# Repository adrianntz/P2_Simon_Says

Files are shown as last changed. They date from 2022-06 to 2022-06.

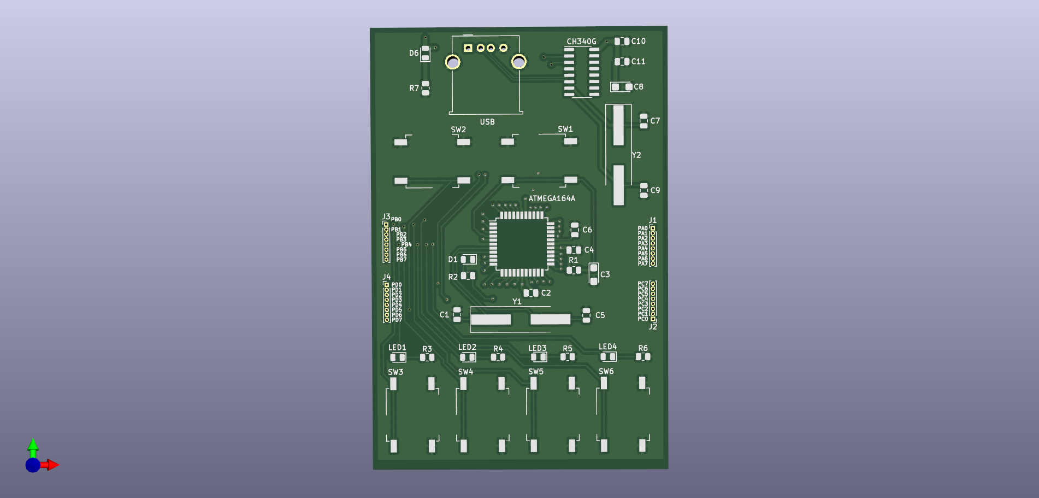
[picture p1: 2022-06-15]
Hardware/Simon Says PCB Layout.png

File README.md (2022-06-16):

# P2_Simon_Says
Proiect Simplu proiectat cu microcontroller AVR ATMEGA164A pentru a creea un joc simplu de tip Simon Says, folosind 4 butoane pentru user input si 4 led-uri pentru system output. 

## Inspiratie Proiect
Ideea de functionare a jocului a fost preluata din acest proiect pe arduino:

IMAGE ALT TEXT HERE (https://www.youtube.com/watch?v=xLLTxN_UBnI)

https://youtu.be/xLLTxN_UBnI

## Firmware Architecture
Bootloader-ul pentru Atmega164A este deja incarcat inainte de primirea chip-ului. Firmware-ul poate fi flashed folosind programul AvrBuster.exe
Firmware-ul pentru Atmega164A este scris in C folosind compilatorul CodeVisionAVR ANSI C Compiler si IDE-ul CodeVisionAVR. Codul in C  a fost creat folosind Code Wizard-ul IDE-ului.
Pentru jocul Simon Says vom folosi doar Portul B al microcontrollerului. Astfel, cu Code Wizard am initializat Pinii PB0->3 ca input si conectati la rezistorul pull-up intern, acesti pini fiind conectati la switch-uri, iar pinii PB4->7 sunt de tip output prin care aprindem LED-urile.
Codul are ca structura principala doi vectori de lungime MAX_LEVEL, unul fiind lista de secvente a nivelului si al doilea fiind secventa introdusa de catre jucator.
Astfel, lungimea jocului poate fi setata folosind MAX_LEVEL. La pornirea firmware-ului se umple vectorul nivelului cu valori randomizate intre 0 si 4. De-a lungul jocului se completeaza si vectorul cu secventele introduse de jucator, si se vor compara ce doi vetori. In momentul in care se greseste o secventa sau se ajunge la lungimea maxima, se termina jocul si se reseteaza vectorii.
De asemenea Firmware-ul are implementat o dificultate a jocului, anume viteza afisarii secventei curente. Cu cat este mai avansat jocul intr-o secventa mai mare, aceasta viteza creste, facand jocul mai dificil cu cat te joci mai mult.

Utilizare Memorie Firmware:
EEPROM usage: 0 byte(s), 0.0% of EEPROM

Program size: 646 words (1292 bytes), 7.9% of FLASH

RAM Global variables size: 404 byte(s)

Estimated Data Stack usage: 6 byte(s)

(Informatie data de compilator)

## Hadware Description
Placuta THT este compusa dintr-un microcontroller ATMEGA164A cu footprint THD si componentele sale auxiliare (condensatoare, quartz si un LED pentru verificare), iar portul A al microcontrollerului este impartit jumate in input si output. Jumatea de input a portului B este conectat la 4 butoane la GND, iar jumatea de output este conectat la 4 led-uri. Alimentarea se face printr-un USB bridge bazat pe chip-ul CH340G USB to Serial Converter.

Varianta SMD introduce un package mai mic pentru toate componentele, ATMEGA164A fiind pe footprint TQFP si toate rezistoarele, condensatoare si led-urile pe footprint 0805. Bridge-ul USB to Serial este incorporat in placuta conectat la un port micro-USB pus pe placuta.
## Hardware Schematic 
Simon Says Schematic
## Hardware PCB Layout


## BOM 

| Component Count: | 39 | | | |
|---|---|---|---|---|
| Ref | Qnty | Value | Footprint | Description |
| C1, C5, | 2 | 18p | Capacitor_SMD:C_0805_2012Metric | Capacitor symbol for simulation only |
| C2, C4, C6, C11, | 4 | 100n | Capacitor_SMD:C_0805_2012Metric | Capacitor symbol for simulation only |
| C3, | 1 | 1u | Capacitor_Tantalum_SMD:CP_EIA-3216-18_Kemet-A | Polarized capacitor |
| C7, C9, | 2 | 22p | Capacitor_SMD:C_0805_2012Metric | Capacitor symbol for simulation only |
| C8, | 1 | 22u | Capacitor_Tantalum_SMD:CP_EIA-3216-12_Kemet-S | Capacitor symbol for simulation only |
| C10, | 1 | 10n | Capacitor_SMD:C_0805_2012Metric | Capacitor symbol for simulation only |
| D1, | 1 | RED LED | LED_SMD:LED_0805_2012Metric | Light emitting diode |
| D2, D6, | 2 | RED  LED | LED_SMD:LED_0805_2012Metric | Light emitting diode |
| D3, | 1 | GEEN LED | LED_SMD:LED_0805_2012Metric | Light emitting diode |
| D4, | 1 | BLUE LED | LED_SMD:LED_0805_2012Metric | Light emitting diode |
| D5, | 1 | ORANGE LED | LED_SMD:LED_0805_2012Metric | Light emitting diode |
| J1, J2, J3, J4, | 4 | Conn_01x08_Female | Connector_PinHeader_1.00mm:PinHeader_1x08_P1.00mm_Vertical | Generic 1x8 Connector |
| J5, | 1 | USB_A | Connector_USB:USB_A_Molex_67643_Horizontal | USB Type A connector |
| R1, | 1 | 10k | Resistor_SMD:R_0805_2012Metric | Resistor |
| R2, | 1 | 470 | Resistor_SMD:R_0805_2012Metric | Resistor |
| R3, R4, R5, R6, | 4 | 100 | Resistor_SMD:R_0805_2012Metric | Resistor |
| R7, | 1 | 220 | Resistor_SMD:R_0805_2012Metric | Resistor |
| SW1, SW2, SW3, SW4, SW5, SW6,  | 6 | SW_MEC_5G | Button_Switch_SMD:SW_MEC_5GSH9 | MEC 5G single pole normally-open tactile switch |
| U1, | 1 | ATmega16A-AU | Package_QFP:TQFP-44_10x10mm_P0.8mm | 16MHz, 16kB Flash, 1kB SRAM, 512B EEPROM, JTAG, TQFP-44 |
| U2, | 1 | CH340G | Package_SO:SOIC-16_3.9x9.9mm_P1.27mm | USB serial converter, UART, SOIC-16 |
| Y1, | 1 | 20MHz | Crystal:Crystal_SMD_HC49-SD_HandSoldering | Two pin crystal |
| Y2, | 1 | 12MHz | Crystal:Crystal_SMD_HC49-SD_HandSoldering | Two pin crystal |

## Bibliography

https://create.arduino.cc/projecthub/bernieri/genius-game-simon-0e76dc

https://www.youtube.com/watch?v=xLLTxN_UBnI

http://ww1.microchip.com/downloads/en/devicedoc/atmel-8272-8-bit-avr-microcontroller-atmega164a_pa-324a_pa-644a_pa-1284_p_datasheet.pdf

https://cdn.sparkfun.com/datasheets/Dev/Arduino/Other/CH340DS1.PDF

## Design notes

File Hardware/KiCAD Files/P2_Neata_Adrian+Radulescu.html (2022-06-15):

# C:\Users\adyco\OneDrive - Universitatea Politehnica Bucuresti\POLI\ANUL 3 SEM 2\P2\P2 Simon Says Repo\Hardware\P2_Neata_Adrian+Radulescu\P2_Neata_Adrian+Radulescu.sch

6/15/2022 5:18:19 PM

Eeschema (5.1.10)-1

Component Count:39

Ref | Qnty | Value | Part | Footprint | Description | Vendor
C1, C5 | 2 | 18p | pspice:C | Capacitor_SMD:C_0805_2012Metric | Capacitor symbol for simulation only
C2, C4, C6, C11 | 4 | 100n | pspice:C | Capacitor_SMD:C_0805_2012Metric | Capacitor symbol for simulation only
C3 | 1 | 1u | Device:CP | Capacitor_Tantalum_SMD:CP_EIA-3216-18_Kemet-A | Polarized capacitor
C7, C9 | 2 | 22p | pspice:C | Capacitor_SMD:C_0805_2012Metric | Capacitor symbol for simulation only
C8 | 1 | 22u | pspice:C | Capacitor_Tantalum_SMD:CP_EIA-3216-12_Kemet-S | Capacitor symbol for simulation only
C10 | 1 | 10n | pspice:C | Capacitor_SMD:C_0805_2012Metric | Capacitor symbol for simulation only
D1 | 1 | RED LED | Device:LED | LED_SMD:LED_0805_2012Metric | Light emitting diode
D2, D6 | 2 | RED LED | Device:LED | LED_SMD:LED_0805_2012Metric | Light emitting diode
D3 | 1 | GEEN LED | Device:LED | LED_SMD:LED_0805_2012Metric | Light emitting diode
D4 | 1 | BLUE LED | Device:LED | LED_SMD:LED_0805_2012Metric | Light emitting diode
D5 | 1 | ORANGE LED | Device:LED | LED_SMD:LED_0805_2012Metric | Light emitting diode
J1, J2, J3, J4 | 4 | Conn_01x08_Female | Connector:Conn_01x08_Female | Connector_PinHeader_1.00mm:PinHeader_1x08_P1.00mm_Vertical | Generic connector, single row, 01x08, script generated (kicad-library-utils/schlib/autogen/connector/)
J5 | 1 | USB_A | Connector:USB_A | Connector_USB:USB_A_Molex_67643_Horizontal | USB Type A connector
R1 | 1 | 10k | Device:R | Resistor_SMD:R_0805_2012Metric | Resistor
R2 | 1 | 470 | Device:R | Resistor_SMD:R_0805_2012Metric | Resistor
R3, R4, R5, R6 | 4 | 100 | Device:R | Resistor_SMD:R_0805_2012Metric | Resistor
R7 | 1 | 220 | Device:R | Resistor_SMD:R_0805_2012Metric | Resistor
SW1, SW2, SW3, SW4, SW5, SW6 | 6 | SW_MEC_5G | Switch:SW_MEC_5G | Button_Switch_SMD:SW_MEC_5GSH9 | MEC 5G single pole normally-open tactile switch
U1 | 1 | ATmega16A-AU | MCU_Microchip_ATmega:ATmega16A-AU | Package_QFP:TQFP-44_10x10mm_P0.8mm | 16MHz, 16kB Flash, 1kB SRAM, 512B EEPROM, JTAG, TQFP-44
U2 | 1 | CH340G | Interface_USB:CH340G | Package_SO:SOIC-16_3.9x9.9mm_P1.27mm | USB serial converter, UART, SOIC-16
Y1 | 1 | 20MHz | Device:Crystal | Crystal:Crystal_SMD_HC49-SD_HandSoldering | Two pin crystal
Y2 | 1 | 12MHz | Device:Crystal | Crystal:Crystal_SMD_HC49-SD_HandSoldering | Two pin crystal

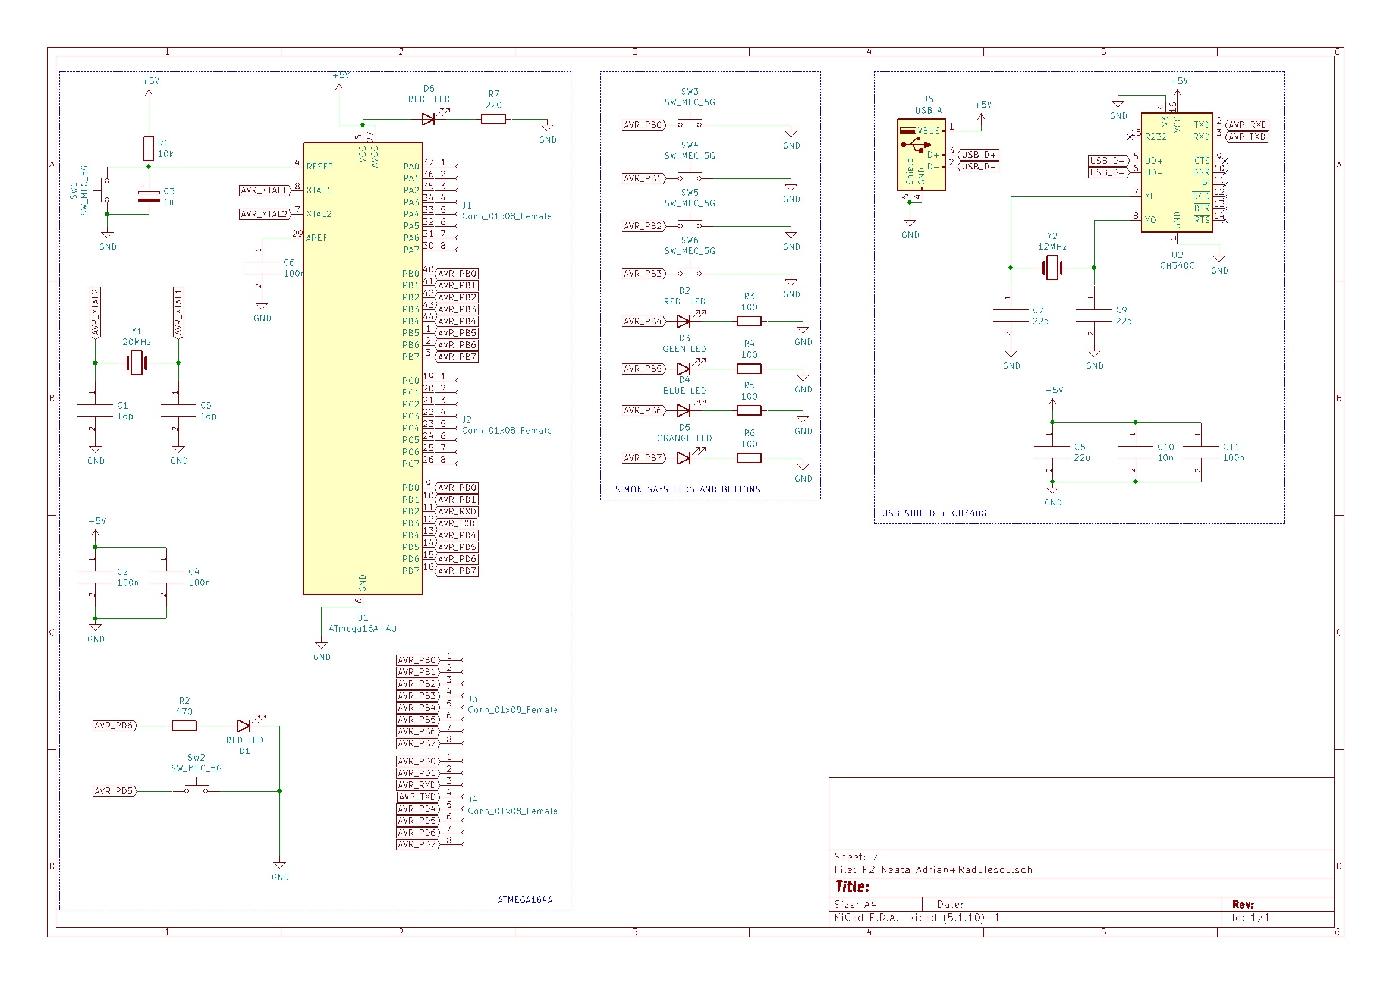
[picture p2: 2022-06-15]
Hardware/Simon Says Schematic.jpg

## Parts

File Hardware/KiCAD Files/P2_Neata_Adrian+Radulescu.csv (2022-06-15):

Source: | C:\Users\adyco\OneDrive - Universitatea Politehnica Bucuresti\POLI\ANUL 3 SEM 2\P2\P2 Simon Says Repo\Hardware\P2_Neata_Adrian+Radulescu\P2_Neata_Adrian+Radulescu.sch
Date: | 6/15/2022 5:18:28 PM
Tool: | Eeschema (5.1.10)-1
Generator: | C:\Program Files\KiCad\bin\scripting\plugins/bom_csv_grouped_by_value_with_fp.py
Component Count: | 39
Ref | Qnty | Value | Cmp name | Footprint | Description | Vendor
C1, C5, | 2 | 18p | C | Capacitor_SMD:C_0805_2012Metric | Capacitor symbol for simulation only
C2, C4, C6, C11, | 4 | 100n | C | Capacitor_SMD:C_0805_2012Metric | Capacitor symbol for simulation only
C3, | 1 | 1u | CP | Capacitor_Tantalum_SMD:CP_EIA-3216-18_Kemet-A | Polarized capacitor
C7, C9, | 2 | 22p | C | Capacitor_SMD:C_0805_2012Metric | Capacitor symbol for simulation only
C8, | 1 | 22u | C | Capacitor_Tantalum_SMD:CP_EIA-3216-12_Kemet-S | Capacitor symbol for simulation only
C10, | 1 | 10n | C | Capacitor_SMD:C_0805_2012Metric | Capacitor symbol for simulation only
D1, | 1 | RED LED | LED | LED_SMD:LED_0805_2012Metric | Light emitting diode
D2, D6, | 2 | RED LED | LED | LED_SMD:LED_0805_2012Metric | Light emitting diode
D3, | 1 | GEEN LED | LED | LED_SMD:LED_0805_2012Metric | Light emitting diode
D4, | 1 | BLUE LED | LED | LED_SMD:LED_0805_2012Metric | Light emitting diode
D5, | 1 | ORANGE LED | LED | LED_SMD:LED_0805_2012Metric | Light emitting diode
J1, J2, J3, J4, | 4 | Conn_01x08_Female | Conn_01x08_Female | Connector_PinHeader_1.00mm:PinHeader_1x08_P1.00mm_Vertical | Generic connector, single row, 01x08, script generated (kicad-library-utils/schlib/autogen/connector/)
J5, | 1 | USB_A | USB_A | Connector_USB:USB_A_Molex_67643_Horizontal | USB Type A connector
R1, | 1 | 10k | R | Resistor_SMD:R_0805_2012Metric | Resistor
R2, | 1 | 470 | R | Resistor_SMD:R_0805_2012Metric | Resistor
R3, R4, R5, R6, | 4 | 100 | R | Resistor_SMD:R_0805_2012Metric | Resistor
R7, | 1 | 220 | R | Resistor_SMD:R_0805_2012Metric | Resistor
SW1, SW2, SW3, SW4, SW5, SW6, | 6 | SW_MEC_5G | SW_MEC_5G | Button_Switch_SMD:SW_MEC_5GSH9 | MEC 5G single pole normally-open tactile switch
U1, | 1 | ATmega16A-AU | ATmega16A-AU | Package_QFP:TQFP-44_10x10mm_P0.8mm | 16MHz, 16kB Flash, 1kB SRAM, 512B EEPROM, JTAG, TQFP-44
U2, | 1 | CH340G | CH340G | Package_SO:SOIC-16_3.9x9.9mm_P1.27mm | USB serial converter, UART, SOIC-16
Y1, | 1 | 20MHz | Crystal | Crystal:Crystal_SMD_HC49-SD_HandSoldering | Two pin crystal
Y2, | 1 | 12MHz | Crystal | Crystal:Crystal_SMD_HC49-SD_HandSoldering | Two pin crystal

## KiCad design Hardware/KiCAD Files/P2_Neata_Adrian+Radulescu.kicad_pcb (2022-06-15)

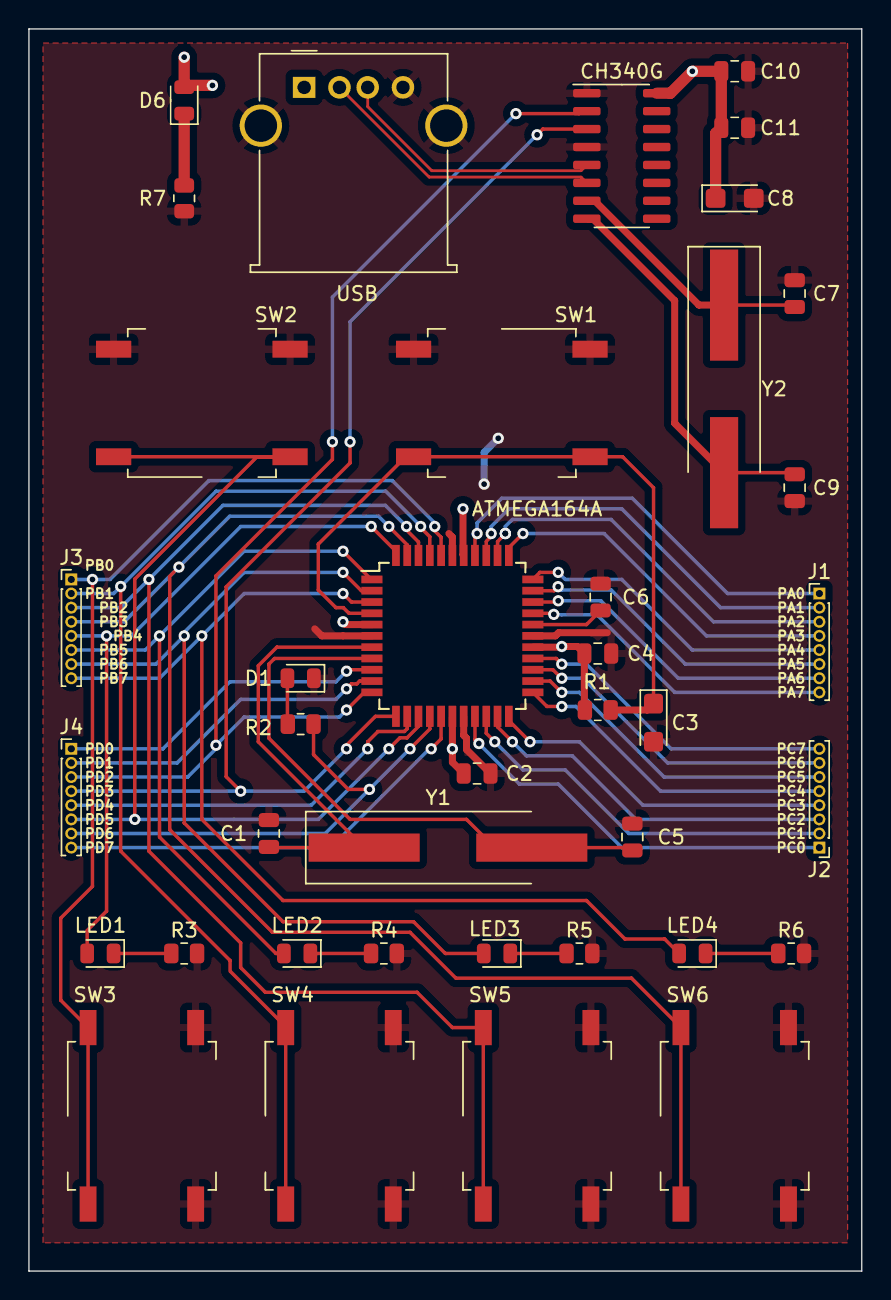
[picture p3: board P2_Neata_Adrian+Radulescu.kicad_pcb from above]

Board: 2 copper layers, 59.0 x 88.0 mm, 39 parts (0 on the bottom side), 48 nets.

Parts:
ATMEGA164A: ATmega16A-AU; TQFP-44_10x10mm_P0.8mm
C1, C5: 18p; C_0805_2012Metric
C2, C4, C6, C11: 100n; C_0805_2012Metric
C3: 1u; CP_EIA-3216-18_Kemet-A
C7, C9: 22p; C_0805_2012Metric
C8: 22u; CP_EIA-3216-12_Kemet-S
C10: 10n; C_0805_2012Metric
CH340G: CH340G; SOIC-16_3.9x9.9mm_P1.27mm
D1, D6: RED LED; LED_0805_2012Metric
J1, J2, J3, J4: Conn_01x08_Female; PinHeader_1x08_P1.00mm_Vertical
LED1: RED LED; LED_0805_2012Metric
LED2: GEEN LED; LED_0805_2012Metric
LED3: BLUE LED; LED_0805_2012Metric
LED4: ORANGE LED; LED_0805_2012Metric
R1: 10k; R_0805_2012Metric
R2: 470; R_0805_2012Metric
R3, R4, R5, R6: 100; R_0805_2012Metric
R7: 220; R_0805_2012Metric
SW1, SW2, SW3, SW4, SW5, SW6: SW_MEC_5G; SW_MEC_5GSH9
USB: USB_A; USB_A_Molex_67643_Horizontal
Y1: 20MHz; Crystal_SMD_HC49-SD_HandSoldering
Y2: 12MHz; Crystal_SMD_HC49-SD_HandSoldering

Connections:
+5V: ATMEGA164A.5, ATMEGA164A.17, ATMEGA164A.27, ATMEGA164A.38, C2.1, C4.1, C8.1, C10.1, C11.1, CH340G.16, D6.2, R1.2, USB.1
AVR_PB0: ATMEGA164A.40, J3.1, SW3.1, SW3.2
AVR_PB1: ATMEGA164A.41, J3.2, SW4.1, SW4.2
AVR_PB2: ATMEGA164A.42, J3.3, SW5.1, SW5.2
AVR_PB3: ATMEGA164A.43, J3.4, SW6.1, SW6.2
AVR_PB4: ATMEGA164A.44, J3.5, LED1.2
AVR_PB5: ATMEGA164A.1, J3.6, LED2.2
AVR_PB6: ATMEGA164A.2, J3.7, LED3.2
AVR_PB7: ATMEGA164A.3, J3.8, LED4.2
AVR_PD0: ATMEGA164A.9, J4.1
AVR_PD1: ATMEGA164A.10, J4.2
AVR_PD4: ATMEGA164A.13, J4.5
AVR_PD5: ATMEGA164A.14, J4.6, SW2.1, SW2.2
AVR_PD6: ATMEGA164A.15, J4.7, R2.1
AVR_PD7: ATMEGA164A.16, J4.8
AVR_RXD: ATMEGA164A.11, CH340G.2, J4.3
AVR_TXD: ATMEGA164A.12, CH340G.3, J4.4
AVR_XTAL1: ATMEGA164A.8, C5.1, Y1.2
AVR_XTAL2: ATMEGA164A.7, C1.1, Y1.1
GND: ATMEGA164A.6, ATMEGA164A.18, ATMEGA164A.28, ATMEGA164A.39, C1.2, C2.2, C3.2, C4.2, C5.2, C6.2, C7.2, C8.2, C9.2, C10.2, C11.2, CH340G.1, CH340G.4, D1.1, R3.2, R4.2, R5.2, R6.2, R7.2, SW1.1, SW1.2, SW2.3, SW2.4, SW3.3, SW3.4, SW4.3, SW4.4, SW5.3, SW5.4, SW6.3, SW6.4, USB.4, USB.5
unnamed: ATMEGA164A.4, C3.1, R1.1, SW1.3, SW1.4
unnamed: ATMEGA164A.29, C6.1
unnamed: C7.1, CH340G.7, Y2.1
unnamed: C9.1, CH340G.8, Y2.2
unnamed: D1.2, R2.2
unnamed: LED1.1, R3.1
unnamed: LED2.1, R4.1
unnamed: LED3.1, R5.1
unnamed: LED4.1, R6.1
unnamed: D6.1, R7.1
unnamed: ATMEGA164A.37, J1.1
unnamed: ATMEGA164A.36, J1.2
unnamed: ATMEGA164A.35, J1.3
unnamed: ATMEGA164A.34, J1.4
unnamed: ATMEGA164A.33, J1.5
unnamed: ATMEGA164A.32, J1.6
unnamed: ATMEGA164A.31, J1.7
unnamed: ATMEGA164A.30, J1.8
unnamed: ATMEGA164A.19, J2.1
unnamed: ATMEGA164A.20, J2.2
unnamed: ATMEGA164A.21, J2.3
unnamed: ATMEGA164A.22, J2.4
unnamed: ATMEGA164A.23, J2.5
unnamed: ATMEGA164A.24, J2.6
unnamed: ATMEGA164A.25, J2.7
unnamed: ATMEGA164A.26, J2.8
USB_D+: CH340G.5, USB.3
USB_D-: CH340G.6, USB.2

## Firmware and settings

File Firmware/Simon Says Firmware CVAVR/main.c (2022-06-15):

/*******************************************************
This program was created by the CodeWizardAVR V3.48b 
Automatic Program Generator
© Copyright 1998-2022 Pavel Haiduc, HP InfoTech S.R.L.
http://www.hpinfotech.ro

Project : 
Version : 
Date    : 5/19/2022
Author  : 
Company : 
Comments: 


Chip type               : ATmega164A
Program type            : Application
AVR Core Clock frequency: 20.000000 MHz
Memory model            : Small
External RAM size       : 0
Data Stack size         : 256
*******************************************************/

// I/O Registers definitions
#include <mega164a.h>
#include <delay.h>
#include <stdlib.h>

#define DATA_REGISTER_EMPTY (1<<UDRE0)
#define RX_COMPLETE (1<<RXC0)
#define FRAMING_ERROR (1<<FE0)
#define PARITY_ERROR (1<<UPE0)
#define DATA_OVERRUN (1<<DOR0)

#define LED1 PORTB.4
#define LED2 PORTB.5
#define LED3 PORTB.6
#define LED4 PORTB.7

#define SW1 PINB.0
#define SW2 PINB.1
#define SW3 PINB.2
#define SW4 PINB.3
#define MAX_LEVEL 100

// Write a character to the USART1 Transmitter
#pragma used+
void putchar1(char c)
{
while ((UCSR1A & DATA_REGISTER_EMPTY)==0);
UDR1=c;
}
#pragma used-

// Declare your global variables here

int Current_Level[MAX_LEVEL];
int Sequence_Input[MAX_LEVEL];
int level = 1;
int Sequence_Step_Delay = 1000;

void All_LED_Off()
{
    LED1=0;
    LED2=0;
    LED3=0;
    LED4=0;
}

void All_LED_On()
{
    LED1=1;
    LED2=1;
    LED3=1;
    LED4=1;
}

void generate_Current_Level() 
{
  
  unsigned int i;
  for ( i = 0; i < MAX_LEVEL; i++) 
    Current_Level[i] = rand() % 4;
    
  
}

void show_Current_Level() 
{
 unsigned int i;
 All_LED_Off();           
 
  for ( i = 0; i < level; i++) 
  { 
   switch(Current_Level[i])
   {
        case 0:
                 LED1=1;
                 delay_ms(Sequence_Step_Delay);
                 LED1=0;
                 delay_ms(200);
        break; 
        case 1:
                LED2=1;
                delay_ms(Sequence_Step_Delay);
                LED2=0;
                delay_ms(200);
        break;
        case 2:
               LED3=1;
               delay_ms(Sequence_Step_Delay);
               LED3=0;
               delay_ms(200);
        break;
        case 3:
               LED4=1;
               delay_ms(Sequence_Step_Delay);
               LED4=0;
               delay_ms(200);
        break;
   } 
   
  }
}

void right_Current_Level() {
  All_LED_Off();
  delay_ms(250);

  All_LED_On();
  delay_ms(500);

  All_LED_Off();
  delay_ms(500);

  if (level < MAX_LEVEL) {
    level++;
  }
  Sequence_Step_Delay -= 50; //increases difficulty
}

void wrong_Current_Level() 
{
  unsigned int i;  
  for ( i = 0; i < 3; i++) 
  {
    All_LED_On();
    delay_ms(250);
    All_LED_Off();
    delay_ms(250);
  }
  
  level = 1;
  Sequence_Step_Delay = 1000;
}

void get_Current_Level() 
{
  int flag = 0; //flag correct Current_Level
  unsigned int i;
  
  for (i = 0; i < level; i++) 
  {
    flag = 0;

    while (flag == 0) 
    {

      if (!SW1) 
      {
        LED1=1;
        delay_ms(Sequence_Step_Delay);
        Sequence_Input[i] = 0;
        flag = 1;
        delay_ms(200);

        if (Sequence_Input[i] != Current_Level[i]) {
          wrong_Current_Level();
          return;
        }
        LED1=0;
      }

      if (!SW2)
       {
        LED2=1;
        delay_ms(Sequence_Step_Delay);
        Sequence_Input[i] = 1;
        flag = 1;
        delay_ms(200);

        if (Sequence_Input[i] != Current_Level[i]) {
          wrong_Current_Level();
          return;
        }
        LED2=0;
      }

      if (!SW3) 
      {
        LED3=1;
        delay_ms(Sequence_Step_Delay);
        Sequence_Input[i] = 2;
        flag = 1;
        delay_ms(200);

        if (Sequence_Input[i] != Current_Level[i]) {
          wrong_Current_Level();
          return;
        }
        LED3=0;
      }

      if (!SW4) {
        LED4=1;
        delay_ms(Sequence_Step_Delay);
        Sequence_Input[i] = 3;
        flag = 1;
        delay_ms(200);

        if (Sequence_Input[i] != Current_Level[i]) {
          wrong_Current_Level();
          return;
        }
        LED4=0;
      }
    }
  }                     
  if(i==MAX_LEVEL)
  { 
    for(i=0;i<10;i++)
    { 
        All_LED_Off();
        delay_ms(100);
        All_LED_On();
        delay_ms(100);
    }
    wrong_Current_Level();
        
  }
  else
    right_Current_Level();
}

void Led_Flash()
{
    LED1=1;
    delay_ms(100);
    LED1=0;
    delay_ms(100);
    
    LED2=1;
    delay_ms(100);
    LED2=0;
    delay_ms(100);
    
    LED3=1;
    delay_ms(100);
    LED3=0;
    delay_ms(100);
    
    LED4=1;
    delay_ms(100);
    LED4=0;
    delay_ms(100);
}



void main(void)
{
// Declare your local variables here
// Crystal Oscillator division factor: 1
#pragma optsize-
CLKPR=(1<<CLKPCE);
CLKPR=(0<<CLKPCE) | (0<<CLKPS3) | (0<<CLKPS2) | (0<<CLKPS1) | (0<<CLKPS0);
#ifdef _OPTIMIZE_SIZE_
#pragma optsize+
#endif

// Input/Output Ports initialization
// Port A initialization
// Function: Bit7=In Bit6=In Bit5=In Bit4=In Bit3=In Bit2=In Bit1=In Bit0=In 
DDRA=(0<<DDA7) | (0<<DDA6) | (0<<DDA5) | (0<<DDA4) | (0<<DDA3) | (0<<DDA2) | (0<<DDA1) | (0<<DDA0);
// State: Bit7=T Bit6=T Bit5=T Bit4=T Bit3=T Bit2=T Bit1=T Bit0=T 
PORTA=(0<<PORTA7) | (0<<PORTA6) | (0<<PORTA5) | (0<<PORTA4) | (0<<PORTA3) | (0<<PORTA2) | (0<<PORTA1) | (0<<PORTA0);

// Port B initialization
// Function: Bit7=Out Bit6=Out Bit5=Out Bit4=Out Bit3=In Bit2=In Bit1=In Bit0=In 
DDRB=(1<<DDB7) | (1<<DDB6) | (1<<DDB5) | (1<<DDB4) | (0<<DDB3) | (0<<DDB2) | (0<<DDB1) | (0<<DDB0);
// State: Bit7=0 Bit6=0 Bit5=0 Bit4=0 Bit3=P Bit2=P Bit1=P Bit0=P 
PORTB=(0<<PORTB7) | (0<<PORTB6) | (0<<PORTB5) | (0<<PORTB4) | (1<<PORTB3) | (1<<PORTB2) | (1<<PORTB1) | (1<<PORTB0);

// Port C initialization
// Function: Bit7=In Bit6=In Bit5=In Bit4=In Bit3=In Bit2=In Bit1=In Bit0=In 
DDRC=(0<<DDC7) | (0<<DDC6) | (0<<DDC5) | (0<<DDC4) | (0<<DDC3) | (0<<DDC2) | (0<<DDC1) | (0<<DDC0);
// State: Bit7=T Bit6=T Bit5=T Bit4=T Bit3=T Bit2=T Bit1=T Bit0=T 
PORTC=(0<<PORTC7) | (0<<PORTC6) | (0<<PORTC5) | (0<<PORTC4) | (0<<PORTC3) | (0<<PORTC2) | (0<<PORTC1) | (0<<PORTC0);

// Port D initialization
// Function: Bit7=In Bit6=In Bit5=In Bit4=In Bit3=In Bit2=In Bit1=In Bit0=In 
DDRD=(0<<DDD7) | (0<<DDD6) | (0<<DDD5) | (0<<DDD4) | (0<<DDD3) | (0<<DDD2) | (0<<DDD1) | (0<<DDD0);
// State: Bit7=T Bit6=T Bit5=T Bit4=T Bit3=T Bit2=T Bit1=T Bit0=T 
PORTD=(0<<PORTD7) | (0<<PORTD6) | (0<<PORTD5) | (0<<PORTD4) | (0<<PORTD3) | (0<<PORTD2) | (0<<PORTD1) | (0<<PORTD0);

// Timer/Counter 0 initialization
// Clock source: System Clock
// Clock value: Timer 0 Stopped
// Mode: Normal top=0xFF
// OC0A output: Disconnected
// OC0B output: Disconnected
TCCR0A=(0<<COM0A1) | (0<<COM0A0) | (0<<COM0B1) | (0<<COM0B0) | (0<<WGM01) | (0<<WGM00);
TCCR0B=(0<<WGM02) | (0<<CS02) | (0<<CS01) | (0<<CS00);
TCNT0=0x00;
OCR0A=0x00;
OCR0B=0x00;

// Timer/Counter 1 initialization
// Clock source: System Clock
// Clock value: Timer1 Stopped
// Mode: Normal top=0xFFFF
// OC1A output: Disconnected
// OC1B output: Disconnected
// Noise Canceler: Off
// Input Capture on Falling Edge
// Timer1 Overflow Interrupt: Off
// Input Capture Interrupt: Off
// Compare A Match Interrupt: Off
// Compare B Match Interrupt: Off
TCCR1A=(0<<COM1A1) | (0<<COM1A0) | (0<<COM1B1) | (0<<COM1B0) | (0<<WGM11) | (0<<WGM10);
TCCR1B=(0<<ICNC1) | (0<<ICES1) | (0<<WGM13) | (0<<WGM12) | (0<<CS12) | (0<<CS11) | (0<<CS10);
TCNT1H=0x00;
TCNT1L=0x00;
ICR1H=0x00;
ICR1L=0x00;
OCR1AH=0x00;
OCR1AL=0x00;
OCR1BH=0x00;
OCR1BL=0x00;

// Timer/Counter 2 initialization
// Clock source: System Clock
// Clock value: Timer2 Stopped
// Mode: Normal top=0xFF
// OC2A output: Disconnected
// OC2B output: Disconnected
ASSR=(0<<EXCLK) | (0<<AS2);
TCCR2A=(0<<COM2A1) | (0<<COM2A0) | (0<<COM2B1) | (0<<COM2B0) | (0<<WGM21) | (0<<WGM20);
TCCR2B=(0<<WGM22) | (0<<CS22) | (0<<CS21) | (0<<CS20);
TCNT2=0x00;
OCR2A=0x00;
OCR2B=0x00;

// Timer/Counter 0 Interrupt(s) initialization
TIMSK0=(0<<OCIE0B) | (0<<OCIE0A) | (0<<TOIE0);

// Timer/Counter 1 Interrupt(s) initialization
TIMSK1=(0<<ICIE1) | (0<<OCIE1B) | (0<<OCIE1A) | (0<<TOIE1);

// Timer/Counter 2 Interrupt(s) initialization
TIMSK2=(0<<OCIE2B) | (0<<OCIE2A) | (0<<TOIE2);

// External Interrupt(s) initialization
// INT0: Off
// INT1: Off
// INT2: Off
// Interrupt on any change on pins PCINT0-7: Off
// Interrupt on any change on pins PCINT8-15: Off
// Interrupt on any change on pins PCINT16-23: Off
// Interrupt on any change on pins PCINT24-31: Off
EICRA=(0<<ISC21) | (0<<ISC20) | (0<<ISC11) | (0<<ISC10) | (0<<ISC01) | (0<<ISC00);
EIMSK=(0<<INT2) | (0<<INT1) | (0<<INT0);
PCICR=(0<<PCIE3) | (0<<PCIE2) | (0<<PCIE1) | (0<<PCIE0);

// USART0 initialization
// USART0 disabled
UCSR0B=(0<<RXCIE0) | (0<<TXCIE0) | (0<<UDRIE0) | (0<<RXEN0) | (0<<TXEN0) | (0<<UCSZ02) | (0<<RXB80) | (0<<TXB80);

// USART1 initialization
// Communication Parameters: 8 Data, 1 Stop, No Parity
// USART1 Receiver: Off
// USART1 Transmitter: On
// USART1 Mode: Asynchronous
// USART1 Baud Rate: 9600
UCSR1A=(0<<RXC1) | (0<<TXC1) | (0<<UDRE1) | (0<<FE1) | (0<<DOR1) | (0<<UPE1) | (0<<U2X1) | (0<<MPCM1);
UCSR1B=(0<<RXCIE1) | (0<<TXCIE1) | (0<<UDRIE1) | (0<<RXEN1) | (1<<TXEN1) | (0<<UCSZ12) | (0<<RXB81) | (0<<TXB81);
UCSR1C=(0<<UMSEL11) | (0<<UMSEL10) | (0<<UPM11) | (0<<UPM10) | (0<<USBS1) | (1<<UCSZ11) | (1<<UCSZ10) | (0<<UCPOL1);
UBRR1H=0x00;
UBRR1L=0x81;

// Analog Comparator initialization
// Analog Comparator: Off
// The Analog Comparator's positive input is
// connected to the AIN0 pin
// The Analog Comparator's negative input is
// connected to the AIN1 pin
ACSR=(1<<ACD) | (0<<ACBG) | (0<<ACO) | (0<<ACI) | (0<<ACIE) | (0<<ACIC) | (0<<ACIS1) | (0<<ACIS0);
ADCSRB=(0<<ACME);
// Digital input buffer on AIN0: On
// Digital input buffer on AIN1: On
DIDR1=(0<<AIN0D) | (0<<AIN1D);

// ADC initialization
// ADC disabled
ADCSRA=(0<<ADEN) | (0<<ADSC) | (0<<ADATE) | (0<<ADIF) | (0<<ADIE) | (0<<ADPS2) | (0<<ADPS1) | (0<<ADPS0);

// SPI initialization
// SPI disabled
SPCR=(0<<SPIE) | (0<<SPE) | (0<<DORD) | (0<<MSTR) | (0<<CPOL) | (0<<CPHA) | (0<<SPR1) | (0<<SPR0);

// TWI initialization
// TWI disabled
TWCR=(0<<TWEA) | (0<<TWSTA) | (0<<TWSTO) | (0<<TWEN) | (0<<TWIE);

while (1)
    {
     if (level == 1) 
     {
        generate_Current_Level();
        Led_Flash();
     }

     if ( (SW1==0) || (level != 1))
      { 
        show_Current_Level();
        get_Current_Level();
      } 

    }

}

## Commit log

2022-06-15 First Commit: Added initial Firmware, Hardware Schematic and layout and Documentation files to the repository.
    [P2_Neata_Adrian+Radulescu.kicad_pcb, P2_Neata_Adrian+Radulescu.sch, simonsays.cfg]
2022-06-15 2nd Commit: Added BOM Files for the hardware schematic.
    [P2_Neata_Adrian+Radulescu.csv, P2_Neata_Adrian+Radulescu.kicad_pcb, P2_Neata_Adrian+Radulescu.sch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]
2022-06-15 Added PCB lauyout files and updated HTML Documentation
    [P2_Neata_Adrian+Radulescu-B_Cu.gbr, P2_Neata_Adrian+Radulescu-B_Mask.gbr, P2_Neata_Adrian+Radulescu-B_Paste.gbr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]
2022-06-15 Added PCB Layout picture to Hardware files
    [P2_Simon_Says_BOM.csv]
